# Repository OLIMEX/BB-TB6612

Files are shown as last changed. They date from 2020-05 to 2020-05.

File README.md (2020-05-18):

# BB-TB6612
Dual DC motor driver board for motors up to 12V 1.2A

Product page: https://www.olimex.com/Products/Robot-CNC-Parts/MotorDrivers/BB-TB6612/

## Licensee
* Hardware is released under CERN Open Hardware Licence Version 2 -
Strongly Reciprocal
* Software is released under GPL3 Licensee
* Documentation is released under CC BY-SA 3.0

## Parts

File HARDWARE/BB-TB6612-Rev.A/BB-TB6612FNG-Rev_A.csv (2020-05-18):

Id | Designator | Package | Quantity | Designation | Supplier and ref
1 |  | LOGO_RECYCLEBIN_1 | 1
2 |  | LOGO_PBFREE | 1
3 |  | OLIMEX_LOGO_TB | 1
4 |  | LOGO_OPENHARDWARE_8x8 | 1
5 | R1 | R_0603_5MIL_0R(Board_Mounted) | 1 | 0R
6 | CON2 | HN1x5 | 1 | INB
7 | CON1 | HN1x5 | 1 | INA
8 | CON6 | N1_SMD | 1 | BO2
9 | CON5 | N1_SMD | 1 | BO1
10 | CON8 | N1_SMD | 1 | PGND
11 | CON7 | N1_SMD | 1 | VDD
12 | CON4 | N1_SMD | 1 | AO2
13 | CON3 | N1_SMD | 1 | AO1
14 | Ref**,Ref**,Ref**,Ref**,Ref**,Ref** | via_09_07 | 6 | Val**
15 | MountingHoleShield**,MountingHoleShield** | Mounting_hole_Shield_3.3mm | 2 | Mounting_hole_Shield_3.3mm
16 | C2,C3,C4 | C_0603_5MIL_DWS | 3 | 10uF/25V
17 | U1 | SSOP24 | 1 | TB6612FNG

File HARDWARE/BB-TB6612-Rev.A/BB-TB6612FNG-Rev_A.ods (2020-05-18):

Designation | Quantity | Designator | Package
HN1x5 | 2 | CON1, CON2 | HN1x5
????? | 6 | CON3,4,5,6,7,8 | N1_SMD
SMD КОНД 0603 2.2 UF X5R 16VDC 10% | 3 | C2,C3,C4 | C_0603_5MIL_DWS
SMD ИС TB6612FNG | 1 | U1 | SSOP24

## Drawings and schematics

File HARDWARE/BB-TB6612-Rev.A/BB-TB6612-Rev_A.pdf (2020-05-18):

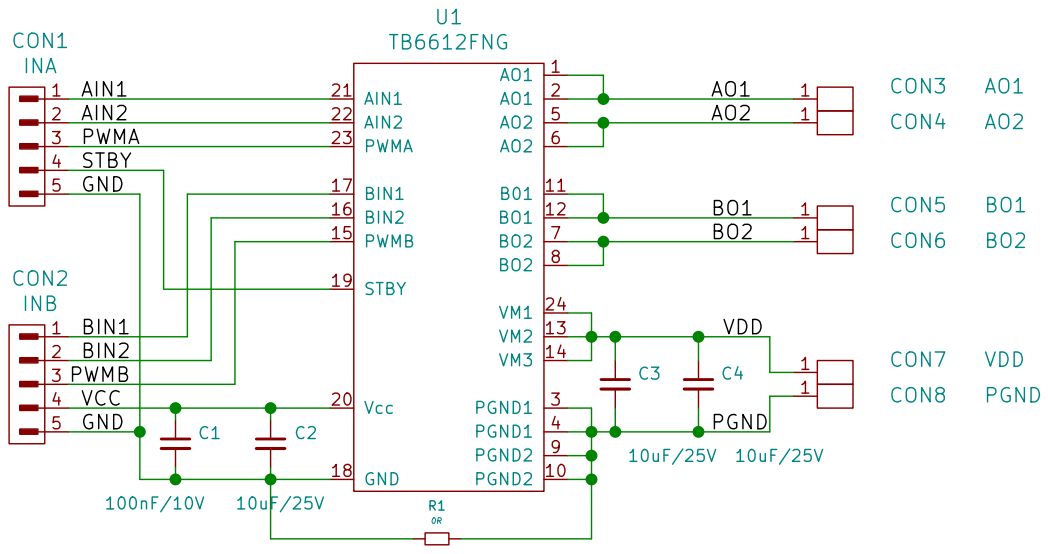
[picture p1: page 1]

File: BB-TB6612FNG-Rev_A.sch Sheet: /
Id: 1/1 Title:

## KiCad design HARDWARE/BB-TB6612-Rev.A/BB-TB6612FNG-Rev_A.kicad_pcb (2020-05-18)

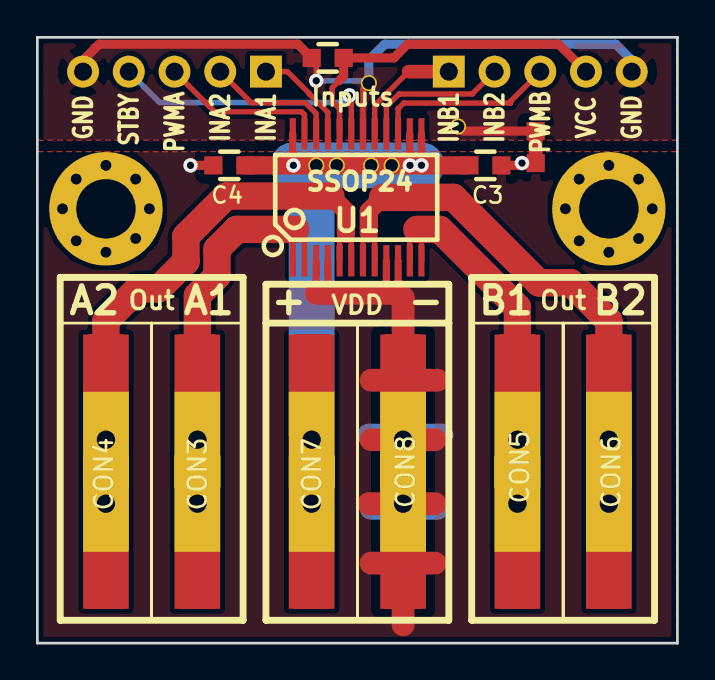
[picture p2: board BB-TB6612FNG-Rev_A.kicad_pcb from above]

Board: 2 copper layers, 35.6 x 33.7 mm, 21 parts (0 on the bottom side), 15 nets.

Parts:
C2, C3, C4: 10uF/25V; C_0603_5MIL_DWS
CON1: INA; HN1x5
CON2: INB; HN1x5
CON3: AO1; N1_SMD
CON4: AO2; N1_SMD
CON5: BO1; N1_SMD
CON6: BO2; N1_SMD
CON7: VDD; N1_SMD
CON8: PGND; N1_SMD
MountingHoleShield**: Mounting_hole_Shield_3.3mm
MountingHoleShield**#2: Mounting_hole_Shield_3.3mm
R1: 0R; R_0603_5MIL_0R(Board_Mounted)
Ref**: Val**; via_09_07
Ref**#2, Ref**#3, Ref**#4, Ref**#5, Ref**#6: Val**; via_09_07
U1: TB6612FNG; SSOP24

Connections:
/AIN1: CON1.1, U1.21
/AIN2: CON1.2, U1.22
/AO1: CON3.1, U1.1, U1.2
/AO2: CON4.1, U1.5, U1.6
/BIN1: CON2.1, U1.17
/BIN2: CON2.2, U1.16
/BO1: CON5.1, U1.11, U1.12
/BO2: CON6.1, U1.7, U1.8
/GND: C2.2, CON1.5, CON2.5, R1.1, Ref**.0, Ref**#2.0, U1.18
/PGND: C3.2, C4.2, CON8.1, R1.2, U1.3, U1.4, U1.9, U1.10
/PWMA: CON1.3, U1.23
/PWMB: CON2.3, U1.15
/STBY: CON1.4, U1.19
/VCC: C2.1, CON2.4, U1.20
/VDD: C3.1, C4.1, CON7.1, Ref**#3.0, Ref**#4.0, Ref**#5.0, Ref**#6.0, U1.13, U1.14, U1.24

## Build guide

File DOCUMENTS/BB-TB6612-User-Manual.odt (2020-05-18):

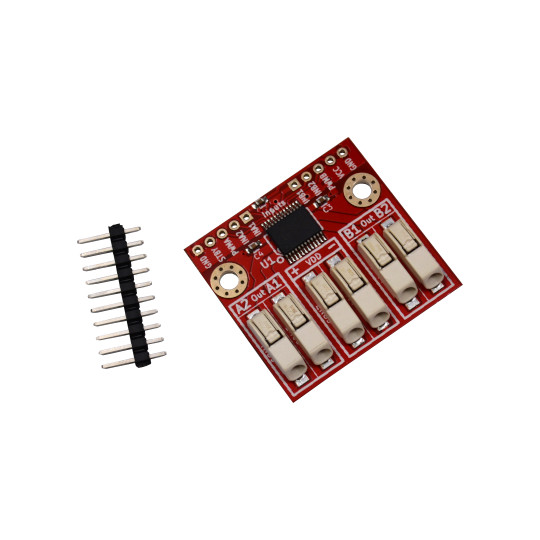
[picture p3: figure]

BB-TB6612

User Manual

Rev.1.0 April 2020

olimex.com

# What is BB-TB6612

BB-TB6612 is dual DC motor driver with digital logic working from 2.7 up to 5.5V and motor voltage from 2.5 up to 13.5V

It's perfect for driving small robot cars with M (https://www.olimex.com/Products/Robot-CNC-Parts/GearMotors/MG-6-120/)G-06-120 (https://www.olimex.com/Products/Robot-CNC-Parts/GearMotors/MG-6-120/) or MG-06-48 (https://www.olimex.com/Products/Robot-CNC-Parts/GearMotors/MG-6-48/) with chassis like: ROBOT-3-WHEEL-KIT (https://www.olimex.com/Products/Robot-CNC-Parts/Chassis/ROBOT-3-WHEEL-KIT/), ROBOT-2WD-KIT (https://www.olimex.com/Products/Robot-CNC-Parts/KITS/ROBOT-2WD-KIT/), ROBOT-2WD-KIT2 (https://www.olimex.com/Products/Robot-CNC-Parts/KITS/ROBOT-2WD-KIT2/) and ROBOT-2WDL-KIT (https://www.olimex.com/Products/Robot-CNC-Parts/KITS/ROBOT-2WDL-KIT/) with 12V battery.

These are BB-TB6612 features:

- Digital logic power supply: 2.7-5.5V
- Motor Power supply: 2.5-13.5V
- Output current 1.2(3A max)
- Output ON 0.5ohm
- Power save mode
- CW/CCW motor rotation
- short brake and stop states
- Thermal shut-down
- operating temperature -20 to 85C
- dimensions: 34 x 34 mm

# Software Control modes:

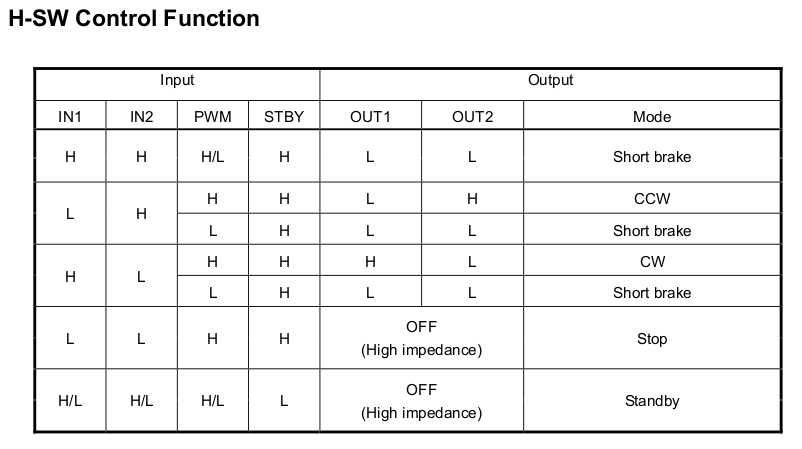
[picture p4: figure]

When STBY is 0 the module enter power saving mode and both motors are released as outputs are in high impedance state.

When IN1 and IN2 are High or if PWM is Low the motors are in Short brake state.

If IN1 is High and IN2 is Low motor turns CW (clock-wise).

If IN1 is Low and IN2 is High motor turns CCW (counter-clock-wise).

If IN1 and IN2 are Low the motor is released as outputs are in high impedance state.

# Typical wiring is:

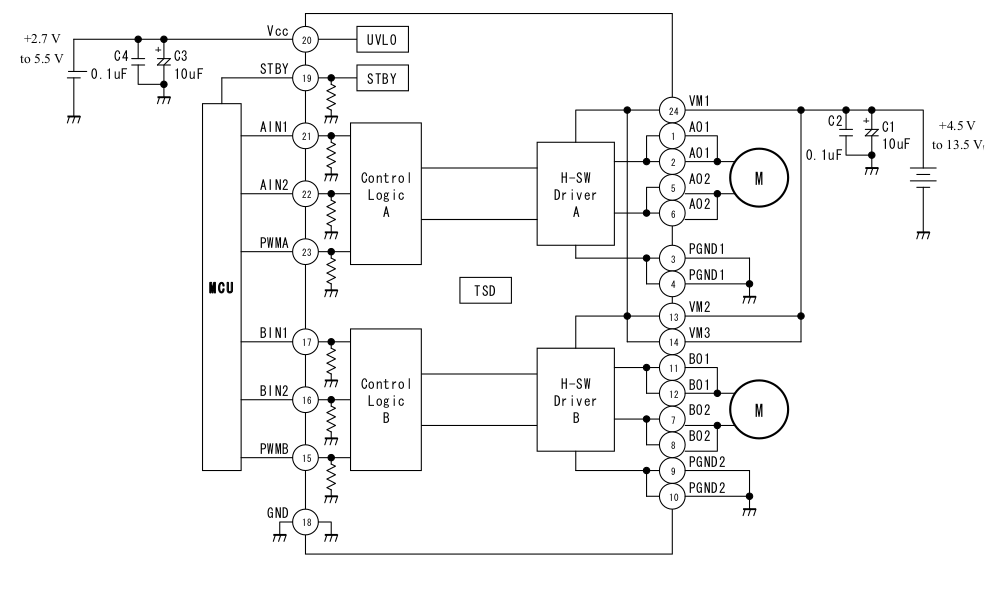
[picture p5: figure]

# Revision History

Revision 1.0 April 2020
